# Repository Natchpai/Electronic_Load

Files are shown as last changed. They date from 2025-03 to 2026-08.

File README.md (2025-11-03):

# DC Electronic Loads Class Project

> A DC electronic load is a test instrument that simulates an electronic load to test the performance of a power source.

This project is **ESP32-Base** (I use esp32 because the processor's clock is fast than ATMega328 on Arduino Family)
ESP32 generating a PWM signal to controls the Gate-Source Voltage of MOSFET to drawn current from a power source, Measurement the currrent and feedback to control loop.

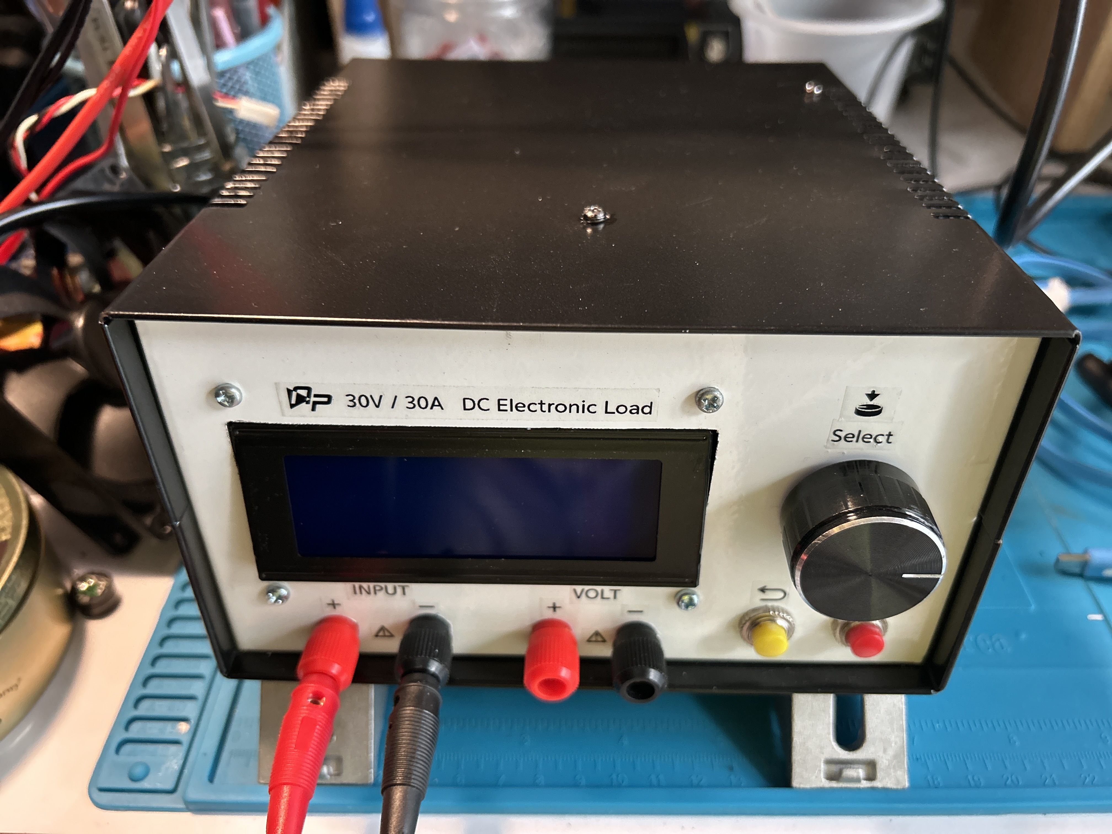
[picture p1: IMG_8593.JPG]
 

## Features
- Constant Current: Max 30A. *(I've only tested at 20A@12V. It works)*
- Constant Power
- Constant Resistance
- Digital Voltmeter(Add-on)

## 🛠️ How It Works
1. Sensing: A shunt resistor I use 0.1 Ohm. Measurement the current by read the voltage across this resister use Op-Amp (OP07)
2. Conversion: The Analog signal from Op-Amp is fed into an External ADC. This chip converts the voltage into a high-resolution digital value.
3. Control: ESP32 reads this digital value from the ADC. Compares this current to set-point and Find the difference between them. It called error.
   A PI controller algorithm running on the ESP32 calculates the exact adjustment needed to eliminate this error.
4. Result: The PI controller's output is a new PWN duty cycle. send to 2nd-order Low pass filter to give the dc level to Gate of MOSFET.

## 🛠️ Schematics
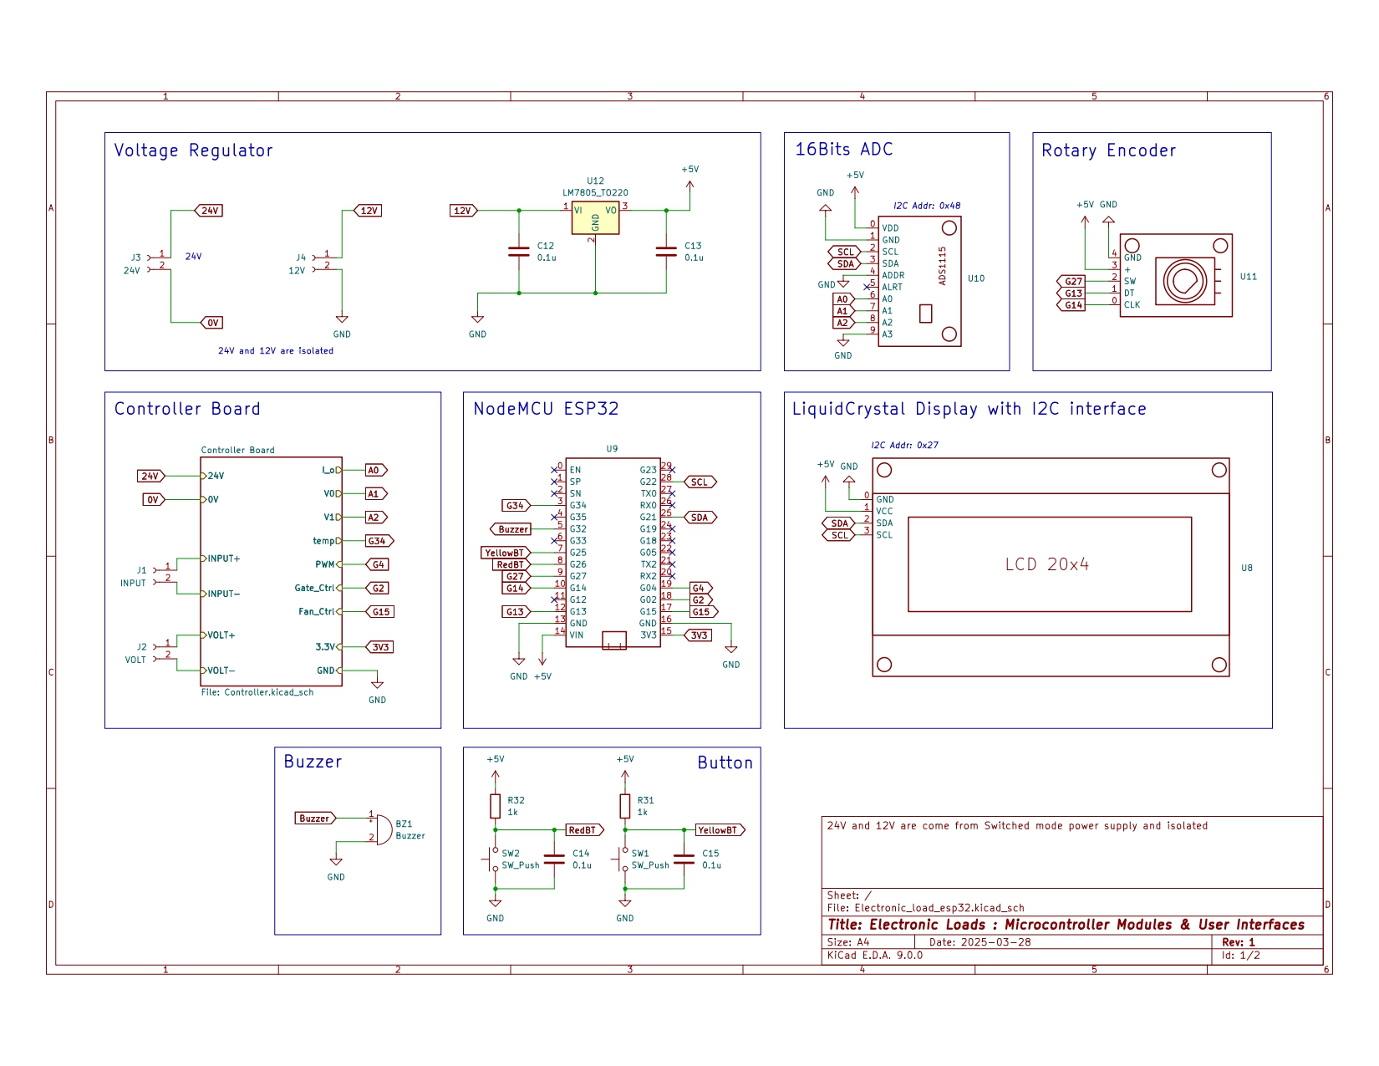
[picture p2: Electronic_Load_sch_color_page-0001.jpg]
sch1

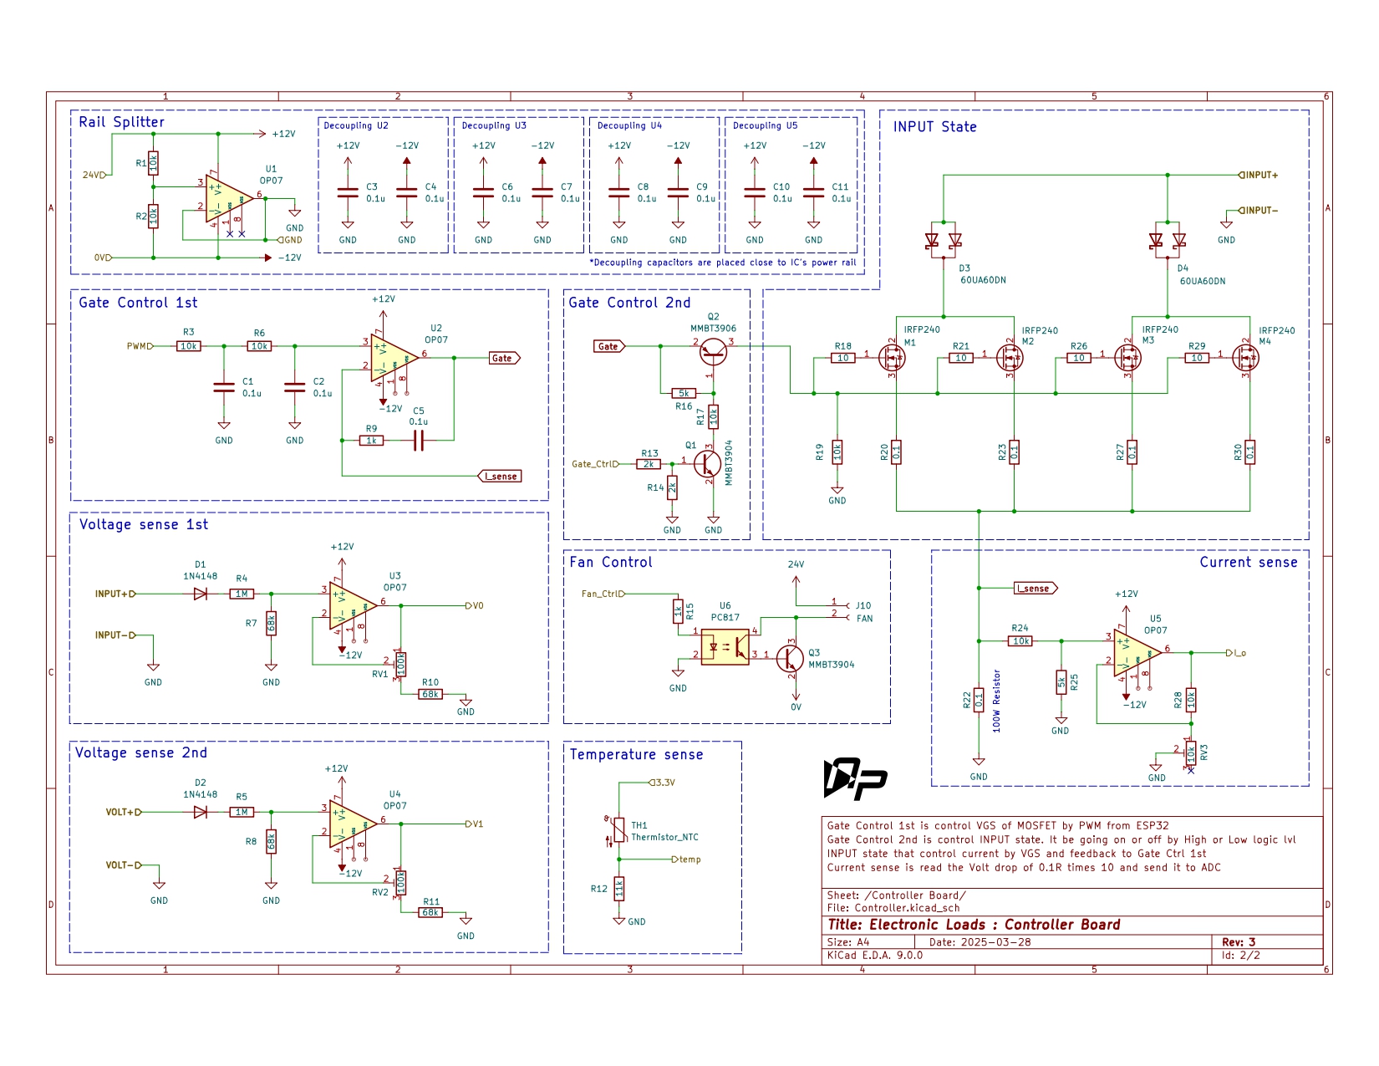
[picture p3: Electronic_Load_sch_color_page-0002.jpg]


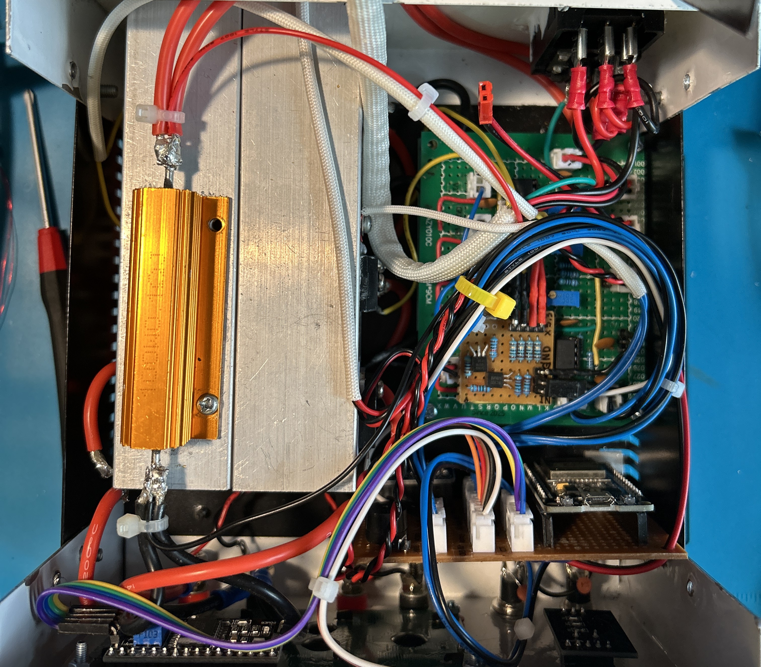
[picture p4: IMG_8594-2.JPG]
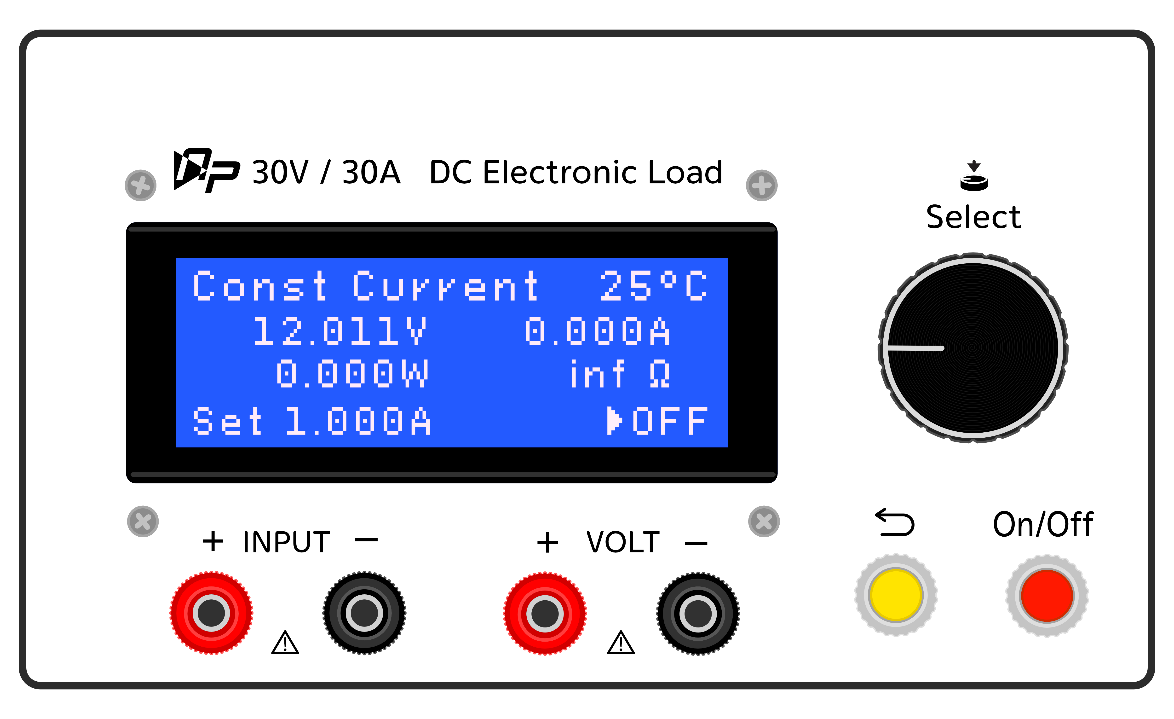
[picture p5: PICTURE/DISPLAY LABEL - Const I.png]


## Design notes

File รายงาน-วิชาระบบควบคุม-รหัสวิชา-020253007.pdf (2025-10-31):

### รายงานวิชาระบบควบคุม รหัสวิชา 0202533007

### เรื่อง โหลดอิเล็กทรอนิกส์ส าหรับไฟฟ้ากระแสตรง

จัดท าโดย

นาย ณัฐชนน เถื่อนถ ้า | 6602027620099
นาย ศิวกร เลิศทวีวัฒนา | 6602027620188
นาย พงศกร วุฒิเวสารัช | 6602027620111

ที่ปรึกษา

ผู้ช่วยศาสตราจารย์ ดร.ชัยยพล ธงชัยสุรัชต์กูล

รายงานนี้เป็นส่วนหนึ่งของวิชาระบบควบคุม

ภาควิชาครุศาสตร์ไฟฟ้า

คณะครุศาสตร์อุตสาหกรรม

มหาวิทยาลัยเทคโนโลยีพระจอมเกล้าพระนครเหนือ

ปีการศึกษา 2567

ก

บทคัดย่อ

โหลดอิเล็กทรอนิกส์กระแสตรง (DC Electronic Loads) เป็นอุปกรณ์ที่ใช้จ ำลองภำระในระบบไฟฟ้ำ กระแสตรงเพื่อทดสอบแหล่งจ่ำยไฟ แบตเตอรี่ เซลล์เชื้อเพลิง และอุปกรณ์อิเล็กทรอนิกส์อื่นๆ โดยสำมำรถปรับ ค่ำกระแส แรงดัน และพลังงำนได้ตำมต้องกำร โหลดอิเล็กทรอนิกส์สำมำรถท ำงำนในหลำยโหมด เช่น โหมดกระแส คงที่ (CC) โหมดก ำลังไฟฟ้ำคงที่ (CP) และโหมดควำมต้ำนทำนคงที่ (CR) ท ำให้สำมำรถจ ำลองกำรใช้งำนที่แตกต่ำง กันได้

กลุ่มของพวกกระผมจึงท ำกำรออกแบบและพัฒนำโหลดอิเล็กทรอนิกส์ที่มีควำมส ำคัญต่ออุตสำหกรรม อิเล็กทรอนิกส์และพลังงำนและยังสอดคล้องกับคณะที่พวกกระผมก ำลังศึกษำ ควำมส ำคัญของโหลดอิเล็กทรอนิกส์ นั่นคือกำรทดสอบประสิทธิภำพและควำมน่ำเชื่อถือของแหล่งจ่ำยไฟฟ้ำ กำรศึกษำครั้งนี้จึงมุ่งเน้นกำรออกแบบ โหลดอิเล็กทรอนิกส์ที่สำมำรถควบคุมได้อย่ำงแม่นย ำผ่ำนไมโครคอนโทรลเลอร์ พร้อมทั้งน ำเสนอกำรวิเครำะห์ สมรรถนะของระบบ ภำยใต้สภำวะโหลดต่ำงๆ

คณะผู้จัดท า

ข

สารบัญ

เรื่อง | หน้า
บทคัดย่อ | ก
สารบัญ | ข

ค

ง

บทที่1

บทน า

### 1. ความเป็นมาและความส าคัญ

ที่มำของโครงงำนเนื่องด้วยข้ำพเจ้ำสังเกตเห็นกลุ่มโครงงำนอื่นได้จัดท ำอุปกรณ์แหล่งจ่ำยข้ำพเจ้ำจึง ตระหนักว่ำในเมื่อมีแหล่งจ่ำยก็ต้องมีโหลดจึงได้จัดท ำโหลดอิเล็กทรอนิกส์ส ำหรับแหล่งจ่ำยไฟตรงซึ่งใช้หำ ประสิทธิภำพก่อนน ำไปใช้งำนจริง และทดสอบระบบของแหล่งจ่ำยว่ำท ำงำนได้อย่ำงมีประสิทธิภำพตำมที่ ออกแบบ ส ำคัญคือ อิเล็กทรอนิกส์โหลดในท้องตลำดนั้นมีรำคำค่อนข้ำงสูง ด้วยเหตุนี้จึงได้เป็นส่วนหนึ่งในที่มำ ของโครงงำนนี้คือ กำรสร้ำงอิเล็กทรอนิกส์โหลดที่สำมำรถให้งำนได้จริงในรำคำที่จับต้องได้

### 2. วัตถุประสงค์ของโครงงาน

2.1 อิเล็กทรอนิกส์โหลดที่สำมำรถให้งำนได้จริงในรำคำที่จับต้องได้

สร้ำงและออกแบบอุปกรณ์เครื่องมือวัดทำงไฟฟ้ำที่สำมำรถใช้งำนได้จริง

2.2 ทดสอบแหล่งจ่ำยพลังงำนไฟฟ้ำ

โหลดอิเล็กทรอนิกส์ช่วยให้สำมำรถทดสอบกำรท ำงำนของแหล่งจ่ำยไฟฟ้ำได้อย่ำงมีประสิทธิภำพ เช่น ตรวจสอบเสถียรภำพของแรงดันและกระแส รวมถึงผลตอบสนองของวงจรเมื่อมีกำรเปลี่ยนแปลง โหลด

2.3 พัฒนำทักษะด้ำนอิเล็กทรอนิกส์และกำรควบคุมระบบ

โครงงำนนี้ช่วยให้นักศึกษำและนักพัฒนำได้เรียนรู้กำรออกแบบวงจรไฟฟ้ำ กำรใช้ออปแอมป์ กำร ใช้มอสเฟต และเทคนิคกำรควบคุมระบบ เช่น PID Controller ในกำรปรับปรุงกำรท ำงำนของระบบ

### 3. ขอบเขตการท าโครงงาน

3.1 กระแสสูงสุด

สำมำรถรับได้สูงสุด 30 แอมแปร์ เนื่องจำกกระแสยิ่งสูง พลังงำนที่ต้องเปลี่ยนเป็นควำมร้อนยิ่งมี มำก ท ำให้เกิดควำมร้อนสูงภำยในชิ้นงำน และข้อจ ำกัดของชิ้นงำนที่มีขนำดเล็ก

3.2 แรงดันสูงสุด

สำมำรถรับได้สูงสุด 30 โวลต์ เนื่องจำกต้องกำรควำมแม่นย ำในกำรวัดแรงดันจึงจ ำเป็นต้องลดย่ำน วัดยิ่งย่ำนวัดยิ่งกว้ำงควำมแม่นย ำยิ่งต ่ำ แต่สำมำรถแก้ได้ด้วยกำรสร้ำงหลำยย่ำนวัด ซึ่งอยู่เหนือขอบเขต ของโครงงำน

### 4. สมมุติฐานการทดลอง

4.1 ตัวแปรต้น

แรงดัน ที่ใช้ควบคุมกระแสอินพุตให้สัมพันธ์กับฟังก์ชันกำรใช้งำน เช่น ต้องกำรกระแสอินพุต 1 แอมแปร์ (A) ต้องให้แรงดันกับระบบ 1 มิลลิโวลต์(mV)

4.2 ตัวแปรตำม

กระแสอินพุต จำกกำรใช้แรงดันควบคุมระบบให้สัมพันธ์กับฟังก์ชันกำรใช้งำน เช่น ให้แรงดันกับ ระบบ 1 มิลลิโวลต์(mV) จะได้กระแสอินพุต 1 แอมแปร์(A)

4.3 ตัวแปรควบคุม

อุณหภูมิที่เปลี่ยนแปลง ควำมร้อนที่เกิดขึ้นในระบบท ำให้กระแสอินพุตเปลี่ยนแปลงตำมอุณหภูมิ

บทที่ 2

เอกสารที่เกี่ยวข้อง

### 1. รายการอุปกรณ์

### 1.1 มอสเฟต (MOSFET)

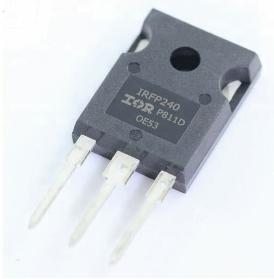
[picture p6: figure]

มอสเฟต เป็นทรำนซิสเตอร์ ที่ใช้อิทธิพลสนำมไฟฟ้ำในกำรควบคุมสัญญำณไฟฟ้ำ โดยใช้ออกไซด์ของ โลหะในกำรท ำ นิยมใช้เป็นสวิตช์เปิด-ปิดในวงจรอิเล็กทรอนิกส์ใช้ในวงจร Switching Power Supply และวงจรควบคุมโหลด

### 1.2 ออปแอมป์ (Op Amp)

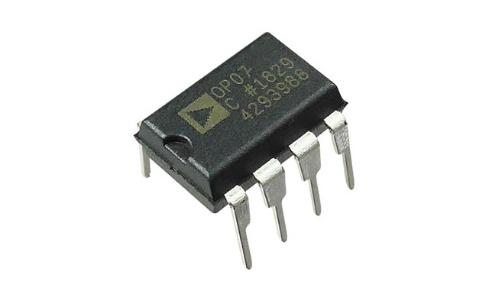
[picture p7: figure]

ออปแอมป์หรือ Operational Amplifier เป็นวงจรขยำยสัญญำณที่มีคุณสมบัติขยำยแรงดันไฟฟ้ำ และสำมำรถน ำไปใช้ในงำนด้ำนอิเล็กทรอนิกส์ได้หลำกหลำย เช่น

1. วงจรขยำยสัญญำณ ใช้ขยำยแรงดันจำกเซนเซอร์หรือไมโครโฟน
2. วงจรเปรียบเทียบแรงดัน ใช้ตรวจสอบระดับแรงดัน เช่น วงจรตรวจจับแรงดันแบตเตอรี่
3. วงจรควบคุม PID Controller หรือวงจรตำมแรงดัน ใช้ในระบบควบคุมอัตโนมัติ

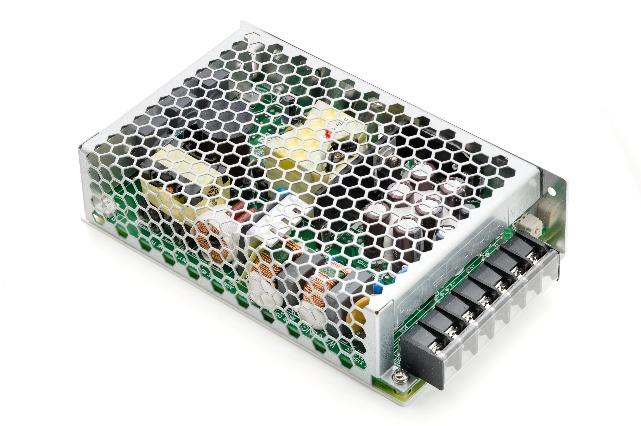
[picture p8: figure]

### 1.2 สวิตชิ่ง (Switched Mode Power Supply)

สวิตชิ่งพำวเวอร์ซัพพลำย หรือ แหล่งจ่ำยไฟฟ้ำแบบสวิตโหมด คือแหล่งจ่ำยไฟที่แปลงแรงดันไฟฟ้ำ โดยใช้หลักกำร เปิดปิดสวิตที่ควำมถี่สูง แทนกำรใช้หม้อแปลงขดลวดใหญ่ท ำให้มีประสิทธิภำพสูง ขนำด เล็ก และน ้ำหนักเบำ โดยมีหลำยแบบเช่น ลดแรงดัน เพิ่มแรงดัน หรือทั้งเพิ่มและทั้งลดแรงดัน เนื่องจำก ต้องสวิตที่ควำมถี่สูง ท ำให้เกิดสัญญำณรบกวนปะปนมำกับแรงดันขำออกด้วย

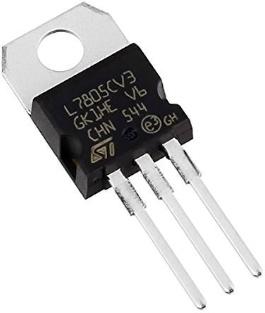
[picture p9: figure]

### 1.3 ไอซีเรกูเลเตอร์แบบเชิงเส้น (Linear Regulator IC)

เป็นวงจรควบคุมรักษำแรงดันไฟฟ้ำ หรือวงจรควบคุมกระแสไฟฟ้ำ ที่ย่อขนำดให้เล็กลงมำอยู่ใน ชิ้นส่วนอิเล็กทรอนิกส์ประเภทไอซี ที่ออกแบบมำเพื่อควบคุมรักษำแรงดันไฟฟ้ำ หรือกระแสไฟให้คงที่ มี ทั้งเอำต์พุตเป็นแรงดันไฟฟ้ำบวก หรือที่เอำต์พุตเป็นแรงดันไฟฟ้ำลบ ทั้งนี้ขึ้นอยู่กับกำรออกแบบสำมำรถ น ำไปใช้ควบคุม ซึ่งข้อดีของเรกูเลเตอร์แบบเชิงเส้นคือ ไม่ท ำให้เกิดสัญญำณรบกวนปะปนมำกับแรงดันขำ ออก

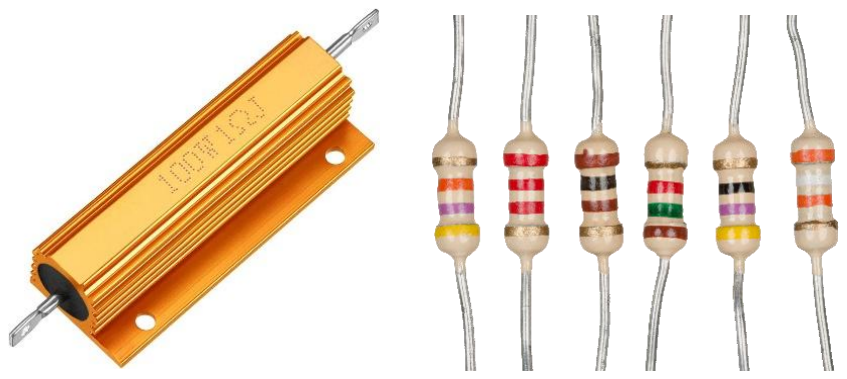
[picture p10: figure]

### 1.4 ตัวต้านทาน (Resistor)

เป็นอุปกรณ์ไฟฟ้ำชนิดหนึ่งที่มีคุณสมบัติในกำรต้ำนกำรไหลผ่ำนของกระแสไฟฟ้ำ ท ำหน้ำที่ลดค่ำ แรงดันไฟฟ้ำ และควบคุมปริมำณอัตรำกำรไหลของกระแสไฟฟ้ำในวงจร ตัวต้ำนทำนมีรูปแบบ และขนำด แตกต่ำงกันตำมลักษณะของกำรใช้งำน นอกจำกนี้ตัวต้ำนทำนที่ผลิตออกมำในปัจจุบันมีมำกมำยหลำย ชนิด น ำมำใช้ประกอบในวงจรทำงด้ำนไฟฟ้ำอิเล็กทรอนิกส์ทั่วไปอย่ำงแพร่หลำย ตัวอย่ำงเช่น เครื่องรับ วิทยุ เครื่องขยำยเสียง โทรทัศน์พำวเวอร์ซัพพลำย เป็นต้น

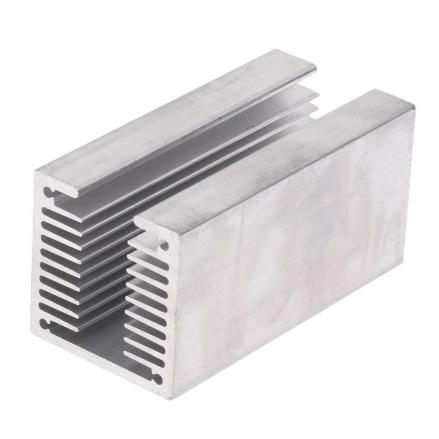
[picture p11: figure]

### 1.5 แผงระบายความร้อน (Heat sink)

แผงระบำยควำมร้อนในระบบอิเล็กทรอนิกส์ เป็นชิ้นส่วนซึ่งท ำหน้ำที่ลดอุณหภูมิขณะท ำงำนของ อุปกรณ์คอมพิวเตอร์หรืออุปกรณ์อิเล็กทรอนิกส์ โดยเพิ่มพื้นที่สัมผัสอำกำศ ท ำให้กำรพำควำมร้อนจำกตัว อุปกรณ์สู่อำกำศโดยรอบท ำได้เร็วขึ้น

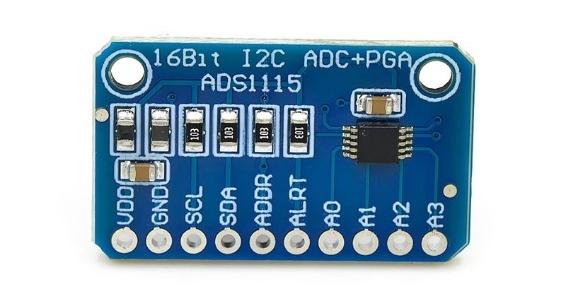
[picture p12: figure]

### 1.6 Analog to Digital Converter (ADC)

ท ำหน้ำที่แปลงสัญญำณแอนะล็อกเป็นลัญญำณดิจิทัล โดยควำมละเอียดนั้นขึ้นอยู่กับจ ำนวนบิตและ แรงดันอ้ำงอิง เช่น
16 บิด แรงดันอ้ำงอิง 4.096 โวลต์สำมำรถหำคงำมละเอียดได้โดย 2 ยกก ำลัง 15ได้ 32,768 และน ำไปหำร 4.096 จะได้ควำมละเอียดคือ 0.000125 โวลต์ต่อ 1 บิต
0000 0000 0000 0001 อ่ำนได้ 0.000125 * 1 แปลงได้ 125 ไมโครโวลต์
0000 0000 0000 0010 อ่ำนได้ 0.000125 * 2 แปลงได้ 250 ไมโครโวลต์
0000 0000 0000 0111 อ่ำนได้ 0.000125 * 7 แปลงได้875 ไมโครโวลต์

### 1.8 NodeMCU ESP32

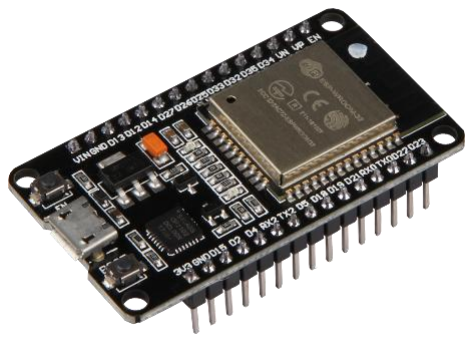
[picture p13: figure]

เป็นบอร์ดไมโครคอนโทรเลอร์ใช้กันอย่ำงแพร่หลำยที่ สำมำรถน ำไปพัฒนำโปรเจ็คได้หลำกหลำย รองรับกำรเชื่อมต่อ Wi-Fi และ Bluetooth ได้โดยไม่ต้องซื้อโมดูลเพิ่มเติม บอร์ด ESP32 เองยังมีกำร
ท ำงำนที่แบ่งเป็น 2 Core และ Pin I/O เลือกฟังก์ชันกำรท ำงำนได้ใน Pin เดียวกัน เช่น กำรแปลง Analog to Digital หรือ Digital to Analog กำรเชื่อมต่อ SD Card หรือ กล้องดิจิทัล ซึ่งสำมำรถเขียน โปรแกรม ผ่ำน Arduino IDE เหมือนเขียน Arduino ได้ข้อดีของ ESP32 นั้นคือ ควำมเร็วมำกกว่ำ และมี ควำมจ ำมำกกว่ำบอร์ดของ Arduino บำงรุ่น

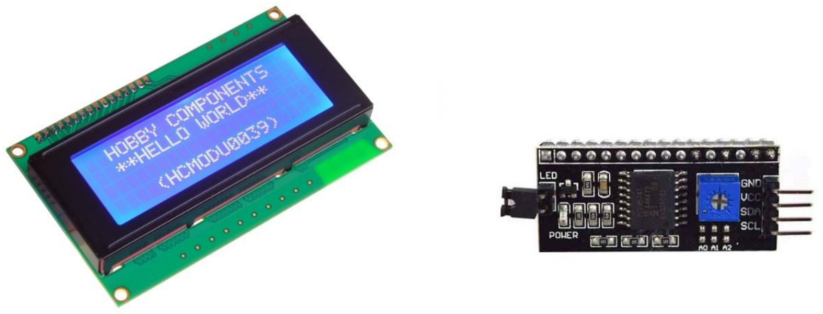
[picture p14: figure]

### 1.9 จอแสดงผล LCD ด้วยรูปแบบการสื่อสาร I²C

เป็นจอแสดงผลผ่ำนโมดูลแปลงรูปแบบกำรเชื่อมต่อแบบขนำนเป็นเชื่อมต่อแบบอื่นที่ใช้สำยน้อย ผ่ำน โปรโตคอล I2C ใช้เพียง 4 เส้น ก็ท ำให้หน้ำจอแสดงผลข้อควำมต่ำงๆออกมำได้

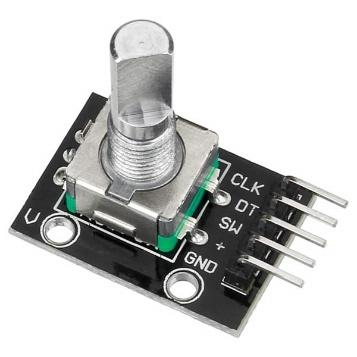
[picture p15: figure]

### 1.10 ตัวเข้ารหัสแบบหมุน (Rotary Encoder)

เป็นอุปกรณ์ไฟฟ้ำกล ที่แปลงต ำแหน่งเชิงมุม หรือกำรเคลื่อนที่ของเพลำหรือแกนหมุนเป็น สัญญำณไฟฟ้ำเอำต์พุต แบบแอนะล็อก หรือ ดิจิทัล

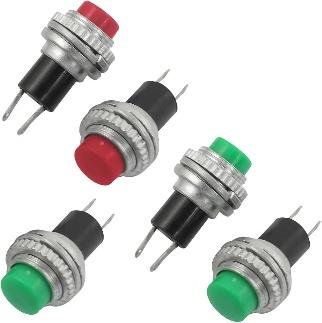
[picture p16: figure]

### 1.11 อินพุตและเอาต์พุตอื่นๆ

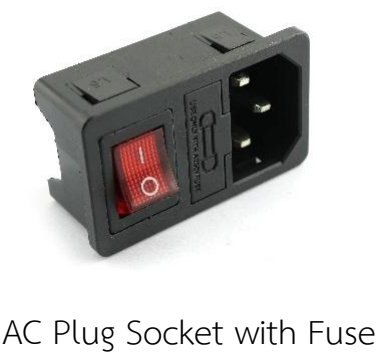
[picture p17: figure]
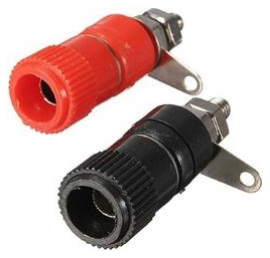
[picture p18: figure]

Push button | Banana Jack Female | AC Plug Socket with Fuse

บทที่ 3

วิธีการด าเนินงาน

### 1. หลักการของโหลดอิเล็กทรอนิกส์

โหลดอิเล็กทรอนิกส์ท ำงำนโดยใช้มอสเฟต (MOSFETs) เป็นตัวควบคุมปริมำณกระแสให้ไหลผ่ำน ตัวมันโดยตั้งใจให้ก ำลังสูญเสียทั้งหมดเกิดขึ้นที่ตัวมอสเฟต โดยก ำลังที่สูญเสียนั้นจะเปลี่ยนเป็นควำมร้อน โดยส่วนใหญ่แล้วมอสเฟตมักจะน ำไปใช้ในเป็นสวิตช์ในวงจรไฟฟ้ำ เช่น ในโซลิดสเตตรีเลย์ซึ่ง
ก ำลังสูญเสียจะค่อนข้ำงต ่ำเนื่องจำกตัวมอสเฟตเองไม่ได้เป็นโหลด โดยสำมำรถทดสอบได้จำกแรงกันตก ค่อมขำ Drain กับ Source เรียกว่ำ VDS คูณกับกระแสที่ไหลผ่ำนขำ Drain เรียกว่ำ ID ได้เป็นก ำลังสูญเสีย แต่ในโหลดอิเล็กทรอนิกส์นั้นไม่ได้ต้องกำรให้มอสเฟตเป็นสวิตช์แต่อย่ำงใด แต่ต้องกำรให้มอสเฟตเป็น โหลด โดยกำรต่อมอสเฟตขนำนกับอินพุต ให้แรงดัน VDS ได้สูงสุดหรือเท่ำกับอินพุต กำรควบคุมก ำลัง สูญเสียนั้นก็จะเหลือแค่กำรคุมกระแสให้ไหลผ่ำนมอสเฟตเท่ำนั้น โดยกำรควบคุมกระแสให้ไหลผ่ำนมอสเฟตได้ตำมต้องกำรนั้น สำมำรถท ำได้โดยกำรควบคุม แรงดันตกค่อมระหว่ำงขำ Gate และ Source เรียกว่ำ VGS โดยยิ่ง VGS มำก กระแสก็จะไหลผ่ำนได้มำก

### 2. การออกแบบ

กำรออกแบบโหลดอิเล็กทรอนิกส์นั้นได้ออกแบบโหมดกำรท ำงำนหลักไว้ 3 รูปแบบ คือ

### 1.1 โหมดกระแสคงที่ (Constant Current หรือ CC)

ท ำงำนโดยกำรควบคุม VGS เพื่อให้มอสเฟตน ำกระแสได้คงที่ตำมค่ำที่ใส่ลงไป

### 1.2 โหมดก าลังคงที่ (Constant Power หรือ CP)

ท ำงำนโดยกำรควบคุม VGS เพื่อให้มอสเฟตน ำกระแสให้สัมพันธ์กับแรงดันอินพุตที่เปลี่ยนไป ตำมสมกำร P = I * V

### 1.3 โหมดความต้านทานคงที่ (Constant Resistance หรือ CR)

ท ำงำนโดยกำรควบคุม VGS เพื่อให้มอสเฟตน ำกระแสให้สัมพันธ์กับแรงดันอินพุตที่เปลี่ยนไป ตำมสมกำร R = V / I

โดยสุดท้ำยแล้วทุกโหมดนั้นเกิดจำกกำรควบคุมกระแสให้ไหลผ่ำนมอสเฟตตำมต้องกำรทั้งสิ้น กำรควบคุมกระแสนั้น ตำมที่กล่ำวมำข้ำงต้นคือกำรควบคุมแรงดันเกตซอร์ซ (VGS) โดยได้ออกแบบระบบ ไว้โดยใช้ออปแอมป์เป็นตัวควบคุม คุณสมบัติอย่ำงง่ำยของออปแอมป์นั้นคือกำรรักษำแรงดันอินพุตบวกกับอินพุตลบให้เท่ำกันเสมอ ในวงปิด กำรใช้คุณสมบัตินี้มำคุมกำรไหลของกระแสได้โดยกำรอ่ำนกระแสที่ไหลในระบบแล้วแปลงเป็น แรงดันไฟฟ้ำส่งมำที่อินพุตของออปแอมป์ โดยกำรแปลงค่ำกระแสเป็นแรงดันนั้นสำมำรถท ำได้โดยกำรต่อ ตัวต้ำนทำนที่มีค่ำต ่ำ อนุกรมไปกับระบบที่ต้องกำรวัดกระแสแล้ววัดแรงดันตกค่อมตัวต้ำนทำนนั้น เช่น ต่อ ตัวต้ำนทำนขนำด 0.1 โอห์มอนุกรมไปกับระบบที่ต้องกำรวัดกระแส จำกนั้นวัดแรงดันตกค่อมตัวต้ำนทำน ถ้ำอ่ำนค่ำได้ 1 โวลต์ แสดงว่ำระบบนี้มีกระแสไหลทั้งหมด 10 แอมป์จำกกฎของโอห์ม กำรใช้คุณสมบัติของออปแอมป์นั้นท ำให้ง่ำยต่อกำรควบคุมระบบ เช่น ถ้ำต้องกำรกระแสไหล 1 แอมป์แสดงว่ำต้องจ่ำยแรงดันให้ออปแอมป์ 0.1 โวลต์เพื่อที่จะได้กระแสไหล 1 แอมป์ เพื่อที่จะได้ระบบที่มีเสถียรภำพมำกขึ้นจึงได้น ำตัวควบคุมพีไอดี(PID Controller) มำใช้ด้วย โดยตัวควบคุมนี้จะอยู่ในส่วนของโปรแกรมควบคุมในไมโครคอนโทรลเลอร์อีกที

ตัวควบคุมแบบสัดส่วน-ปริพันธ์-อนุพันธ์หรือ PID Controller เป็นระบบควบคุมแบบ ป้อนกลับ ซึ่งค่ำที่น ำไปใช้ในกำรค ำนวณเป็นค่ำควำมผิดพลำด มำจำกควำมแตกต่ำงของเอำต์พุตและค่ำที่ ต้องกำร ตัวควบคุมจะพยำยำมลดค่ำผิดพลำดให้เหลือน้อยที่สุด ค่ำ P I D จะขึ้นอยู่กับระบบที่น ำไป ควบคุม

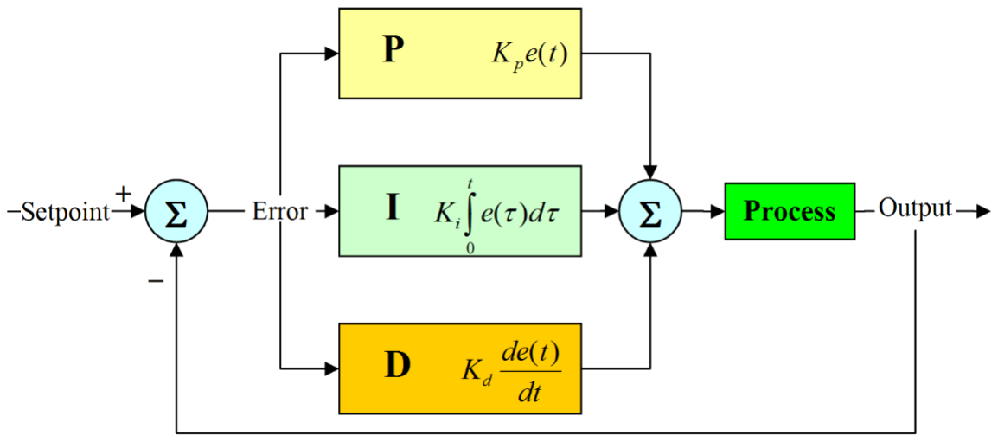
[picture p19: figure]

แผนภำพบล็อกของกำรควบคุมแบบพีไอดี

### 3. วงจร

### 4. การเลือกใช้งาน

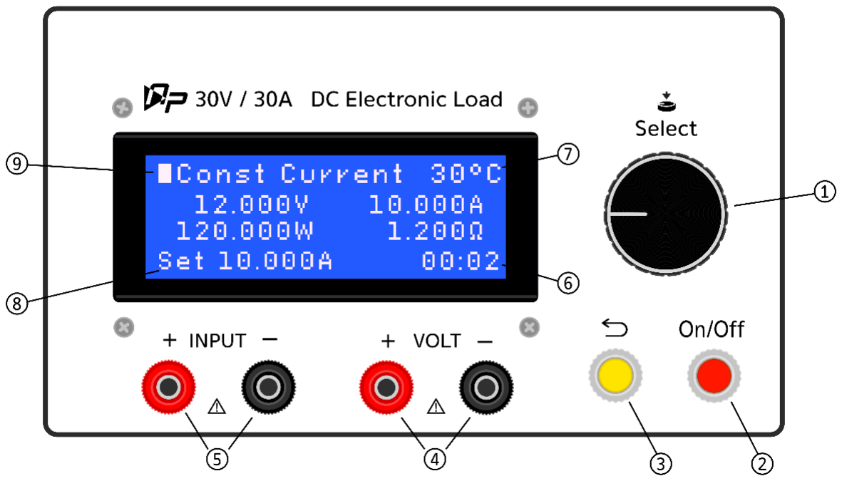
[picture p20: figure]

หมำยเลข 1 : ลูกบิด Select หมุนเพื่อเลื่อน กดเพื่อเลือก
หมำยเลข 2 : ปุ่ม On/Off กด หรือ กดค้ำง เพื่อเปิดกำรท ำงำนในโหมด CC CP และ CR หมำยเลข 3 : ปุ่มย้อนกลับ กด เพื่อ ย้อนกลับ กดค้ำงเพื่อเลือกได้
หมำยเลข 4 : Voltmeter CH1
หมำยเลข 5 : INPUT และ Voltmeter CH0
หมำยเลข 6 : เมื่อปิดจะแสดงค ำว่ำ OFF ถ้ำท ำงำนจะแสดงเวลำตั้งแต่เริ่มกำรท ำงำน หมำยเลข 7 : บอกอุณหภูมิของ Heat sink
หมำยเลข 8 : Setpoint หรือ ค่ำที่ต้องกำร สำมำรถตั้งได้ในโหมด CC CP และ CR หมำยเลข 9 : โหมดปัจจุบัน

### 4.1 Constant Current

1.1 กดปุ่มย้อนกลับเพื่อออกไปหน้ำเลือกฟังก์ชัน
1.2 หมุนลูกบิดให้ลูกศรชี้ที่ Const Current แล้วกดลูกบิด 1 ครั้งยืนยันกำรเลือก 1.3 ถ้ำต้องกำรตั้งค่ำกระแสให้กดลูกบิดอีก 1 ครั้ง เพื่องเข้ำเมนูI Setpoint
1.4 หมุนลูกบิดเลือกค่ำที่ต้องกำร ถ้ำต้องกำรเปลี่ยนหลักให้กดลูกบิด 1 ครั้ง
1.5 กดปุ่มย้อนกลับเพื่อยืนยันค่ำ แล้วเมนูจะเปลี่ยนเป็น Const Current
1.6 กดปุ่ม On/Off เพื่อเปิดหรือปิดใช้งำนโหมดนั้น

### 4.2 Constant Power

1.1 กดปุ่มย้อนกลับเพื่อออกไปหน้ำเลือกฟังก์ชัน
1.2 หมุนลูกบิดให้ลูกศรชี้ที่ Const Power แล้วกดลูกบิด 1 ครั้งยืนยันกำรเลือก 1.3 ถ้ำต้องกำรตั้งค่ำกระแสให้กดลูกบิดอีก 1 ครั้ง เพื่องเข้ำเมนูPower Setpoint 1.4 หมุนลูกบิดเลือกค่ำที่ต้องกำร ถ้ำต้องกำรเปลี่ยนหลักให้กดลูกบิด 1 ครั้ง
1.5 กดปุ่มย้อนกลับเพื่อยืนยันค่ำ แล้วเมนูจะเปลี่ยนเป็น Const Power
1.6 กดปุ่ม On/Off เพื่อเปิดหรือปิดใช้งำนโหมดนั้น

### 4.3 Constant Resistance

1.1 กดปุ่มย้อนกลับเพื่อออกไปหน้ำเลือกฟังก์ชัน
1.2 หมุนลูกบิดให้ลูกศรชี้ที่ Const Resistance แล้วกดลูกบิด 1 ครั้งเพื่อยืนยันกำรเลือก 1.3 ถ้ำต้องกำรตั้งค่ำกระแสให้กดลูกบิดอีก 1 ครั้ง เพื่องเข้ำเมนูR. Setpoint
1.4 หมุนลูกบิดเลือกค่ำที่ต้องกำร ถ้ำต้องกำรเปลี่ยนหลักให้กดลูกบิด 1 ครั้ง
1.5 กดปุ่มย้อนกลับเพื่อยืนยันค่ำ แล้วเมนูจะเปลี่ยนเป็น Constant R.
1.6 กดปุ่ม On/Off เพื่อเปิดหรือปิดใช้งำนโหมดนั้น

### 4.4 Digital Voltmeter

1.1 กดปุ่มย้อนกลับเพื่อออกไปหน้ำเลือกฟังก์ชัน
1.2 หมุนลูกบิดให้ลูกศรชี้ที่ Digital Voltmeter แล้วกดลูกบิด 1 ครั้งยืนยันกำรเลือก 1.3 CH0 วัดจำกช่อง INPUT
1.4 CH1 วัดจำกช่อง VOLT

### 4.5 Utility

1.1 กดปุ่มย้อนกลับเพื่อออกไปหน้ำเลือกฟังก์ชัน
1.2 หมุนลูกบิดให้ลูกศรชี้ที่ Utility แล้วกดลูกบิด 1 ครั้งยืนยันกำรเลือก 1.3 เลือกโดยให้ลูกศรชี้เมนูที่ต้องกำรกดลูกบิด 1 ครั้งยืนยันกำรเลือก

### 4.5.1 Current Max (Default: 20.000A)

เป็นกำรตั้งค่ำกระแสสูงสุดที่ระบบสำมำรถท ำได้ถ้ำใส่ค่ำเกิดในเมนูอื่นๆ กระแสจะไม่เกิน Current Max โดยสำมำรถตั้งได้ 0A – 30A

### 4.5.2 Volt sense (Default: V0)

เป็นกำรเลือก Voltmeter ส ำหรับวัดค่ำแรงดันในโหมด CC CP และ CR
V0 : INPUT เป็น Voltmeter ที่อยู่ในช่อง INPUT
V1 : VOLT เป็น Voltmeter ที่อยู่ในช่อง VOLT จะเป็นต้องต่อสำยวัดเพิ่ม

### 4.5.3 Fan Trig (Default: Auto)

เลือกกำรท ำงำนของพัดลมละบำยควำมร้อน
Auto พัดลมจะท ำงำนเมื่ออุณหภูมิถึง 45°C และจะปิดเมื่ออุณหภูมิลดลงจนถึง 35°C Manual พัดลมจะท ำงำนตำมกำรกดปุ่ม On/Off

### 4.5.4 Runtime Max (Default: 30min)

เป็นกำรตั้งค่ำเวลำ เมื่อโหมด CC CP และ CR ท ำงำนเกินเวลำนี้จะปิดกำรท ำงำนในโหมดนั้น

### 4.5.5 Shutdown Temp (Default: 90°C)

เป็นกำรตั้งค่ำอุณหภูมิสูงสุดภำยในเครื่อง ถ้ำเกิดอุณหภูมิเกินนี้จะปิดกำรท ำงำนในโหมดนั้น

### 4.6 PID Tuner

1.1 กดปุ่มย้อนกลับเพื่อออกไปหน้ำเลือกฟังก์ชัน
1.2 หมุนลูกบิดให้ลูกศรชี้ที่ PID Tuner แล้วกดลูกบิด 1 ครั้งยืนยันกำรเลือก
1.3 หมุนลูกบิดให้ลูกศรชี้ที่ค่ำที่ต้องกำรแล้วกดลูกบิด 1 ครั้งยืนยันกำรเลือก
หมำยเหตุ: ไม่แนะน ำให้ตั้งค่ำ Kp และ Kd ส่วน ค่ำ Ki เมื่อมำกจะท ำให้ระบบตอบสนองเร็วขึ้น ไม่แนะน ำให้เกิด 600 และต ่ำกว่ำ 100 *ค่ำเดิมอยู่ที่ 450

บทที่ 4

สรุปผลและข้อเสนอแนะ

### 1. สรุปผล

1.1 อิเล็กทรอนิกส์โหลดที่สำมำรถให้งำนได้จริงในรำคำที่จับต้องได้สร้ำงและออกแบบอุปกรณ์เครื่องมือวัด ทำงไฟฟ้ำที่สำมำรถใช้งำนได้จริง

1.2 ทดสอบแหล่งจ่ำยพลังงำนไฟฟ้ำโหลดอิเล็กทรอนิกส์ช่วยให้สำมำรถทดสอบกำรท ำงำนของแหล่งจ่ำย ไฟฟ้ำได้อย่ำงมีประสิทธิภำพ เช่น ตรวจสอบเสถียรภำพของแรงดันและกระแส รวมถึงผลตอบสนองของ วงจรเมื่อมีกำรเปลี่ยนแปลงโหลด

1.3 พัฒนำทักษะด้ำนอิเล็กทรอนิกส์และกำรควบคุมระบบ ช่วยให้นักศึกษำและนักพัฒนำได้เรียนรู้ กำรออกแบบวงจรไฟฟ้ำกำรใช้ออปแอมป์กำรใช้มอสเฟตและเทคนิคกำรควบคุมระบบ เช่น
PID Controller ในกำรปรับปรุงกำรท ำงำนของระบบ

### 2. ข้อเสนอแนะและปัญหาในการท างาน

2.1 ด้วยข้อจ ำกัดของชิ้นงำนที่มีขนำดเล็ก กำรท ำงำนด้วยกระแสสุดอำจจ ำให้เกิดควำมร้อนสะสมภำยใน จนอุปกรณ์เสียหำยได้

2.2 ด้วยย่ำนวัดแรงดันที่กว้ำงท ำให้กำรวัดแรงดันคลำดเคลื่อนจำกควำมเป็นจริงเล็กน้อย

2.3 ไม่สำมำรถใช้ควำมสำมำรถ Dual Core ของ ESP32 ได้ ถ้ำใช้ได้ระบบจะเร็วขึ้นอย่ำงเห็นได้ชัด

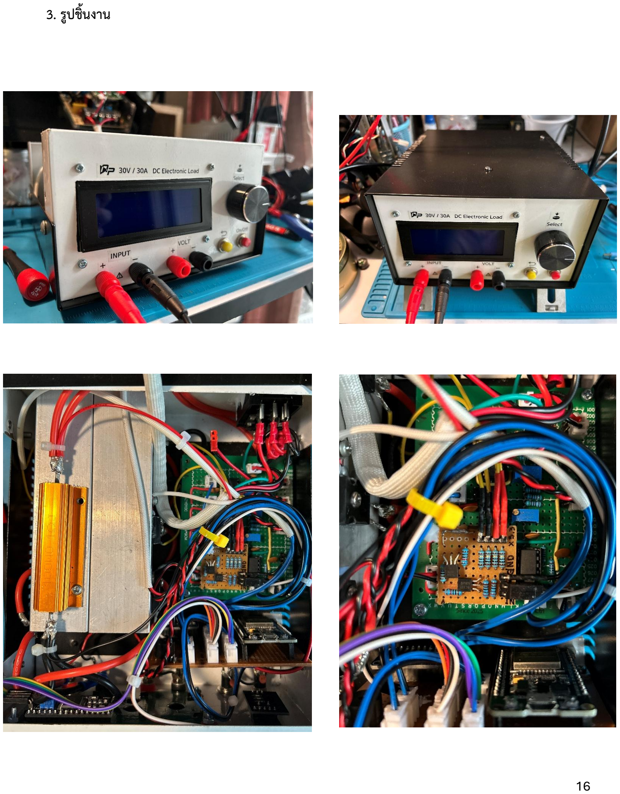
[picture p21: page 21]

### 3. รูปชิ้นงาน

บรรณานุกรม

https://en.wikipedia.org/wiki/Proportional%E2%80%93integral%E2%80%93derivative_controller

https://en.wikipedia.org/wiki/MOSFET

https://en.wikipedia.org/wiki/Operational_amplifier

https://en.wikipedia.org/wiki/Switchedmode_power_supply

https://en.wikipedia.org/wiki/Voltage_regulator

https://en.wikipedia.org/wiki/Resistor

https://en.wikipedia.org/wiki/Analog-to-digital_converter

https://en.wikipedia.org/wiki/ESP32

https://en.wikipedia.org/wiki/Rotary_encoder

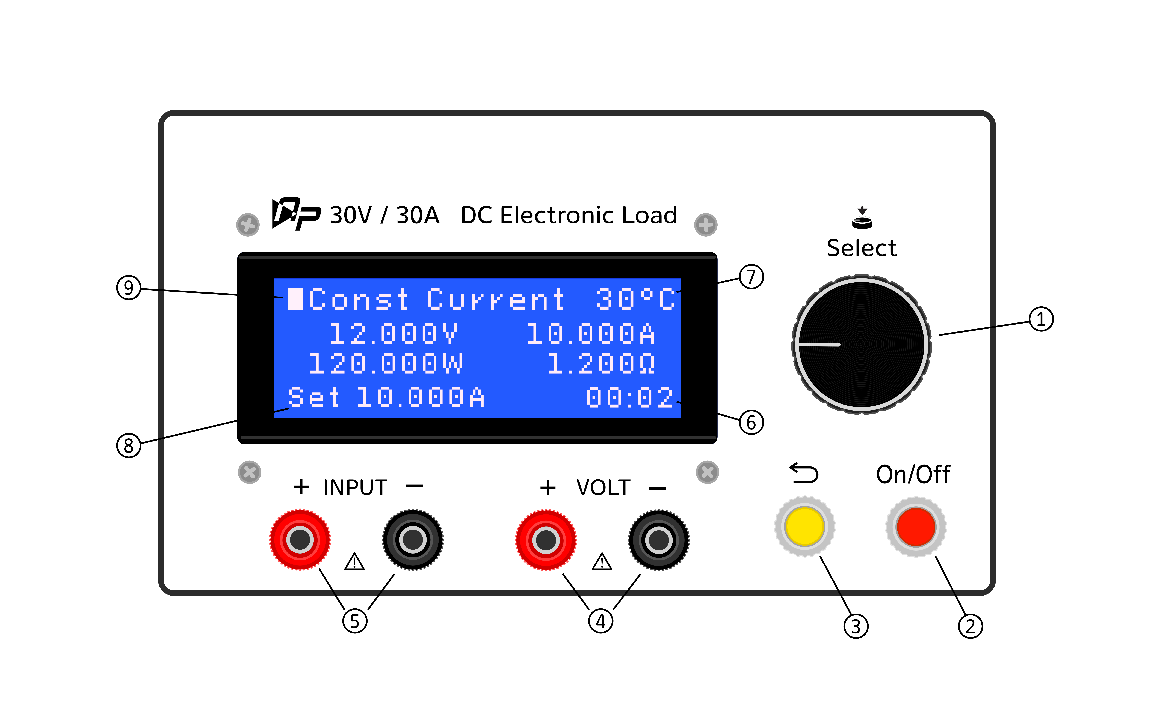
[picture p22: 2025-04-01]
PICTURE/DISPLAY LABEL - nemu_number.png

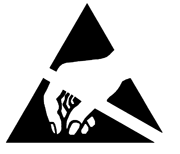
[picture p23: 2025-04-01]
logos/ESDsusceptibilitySymbol.png

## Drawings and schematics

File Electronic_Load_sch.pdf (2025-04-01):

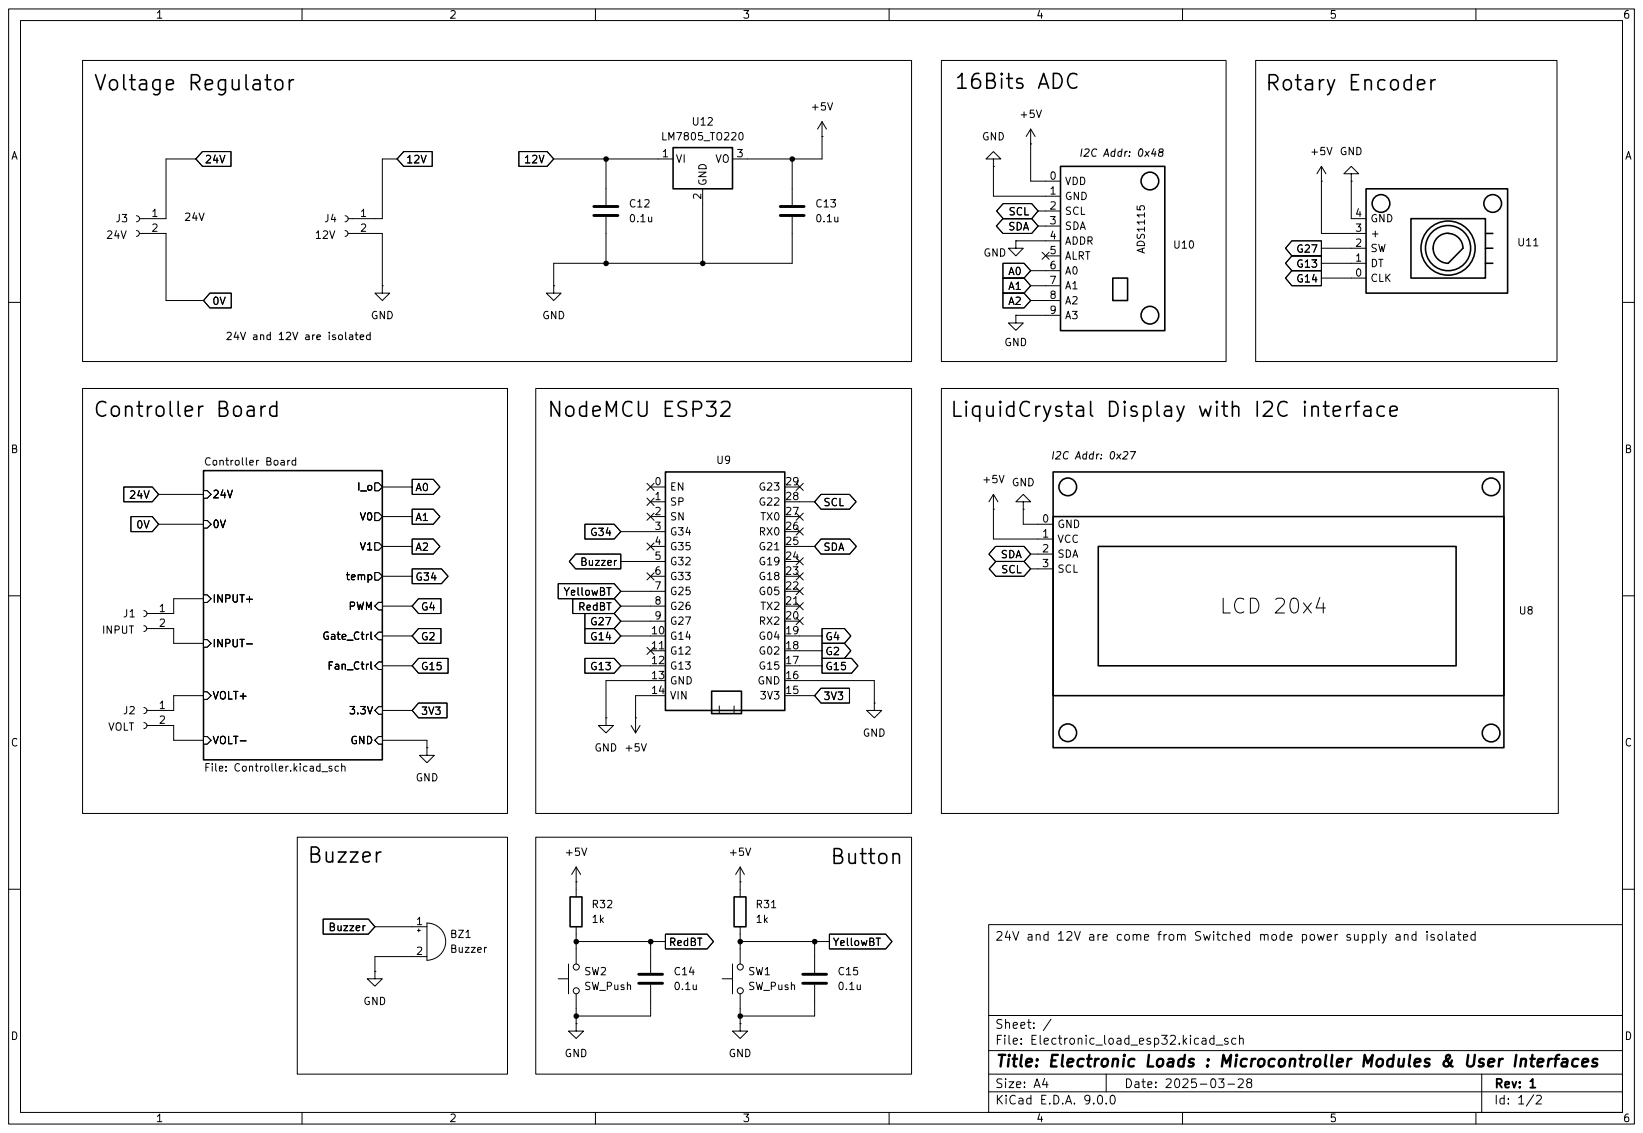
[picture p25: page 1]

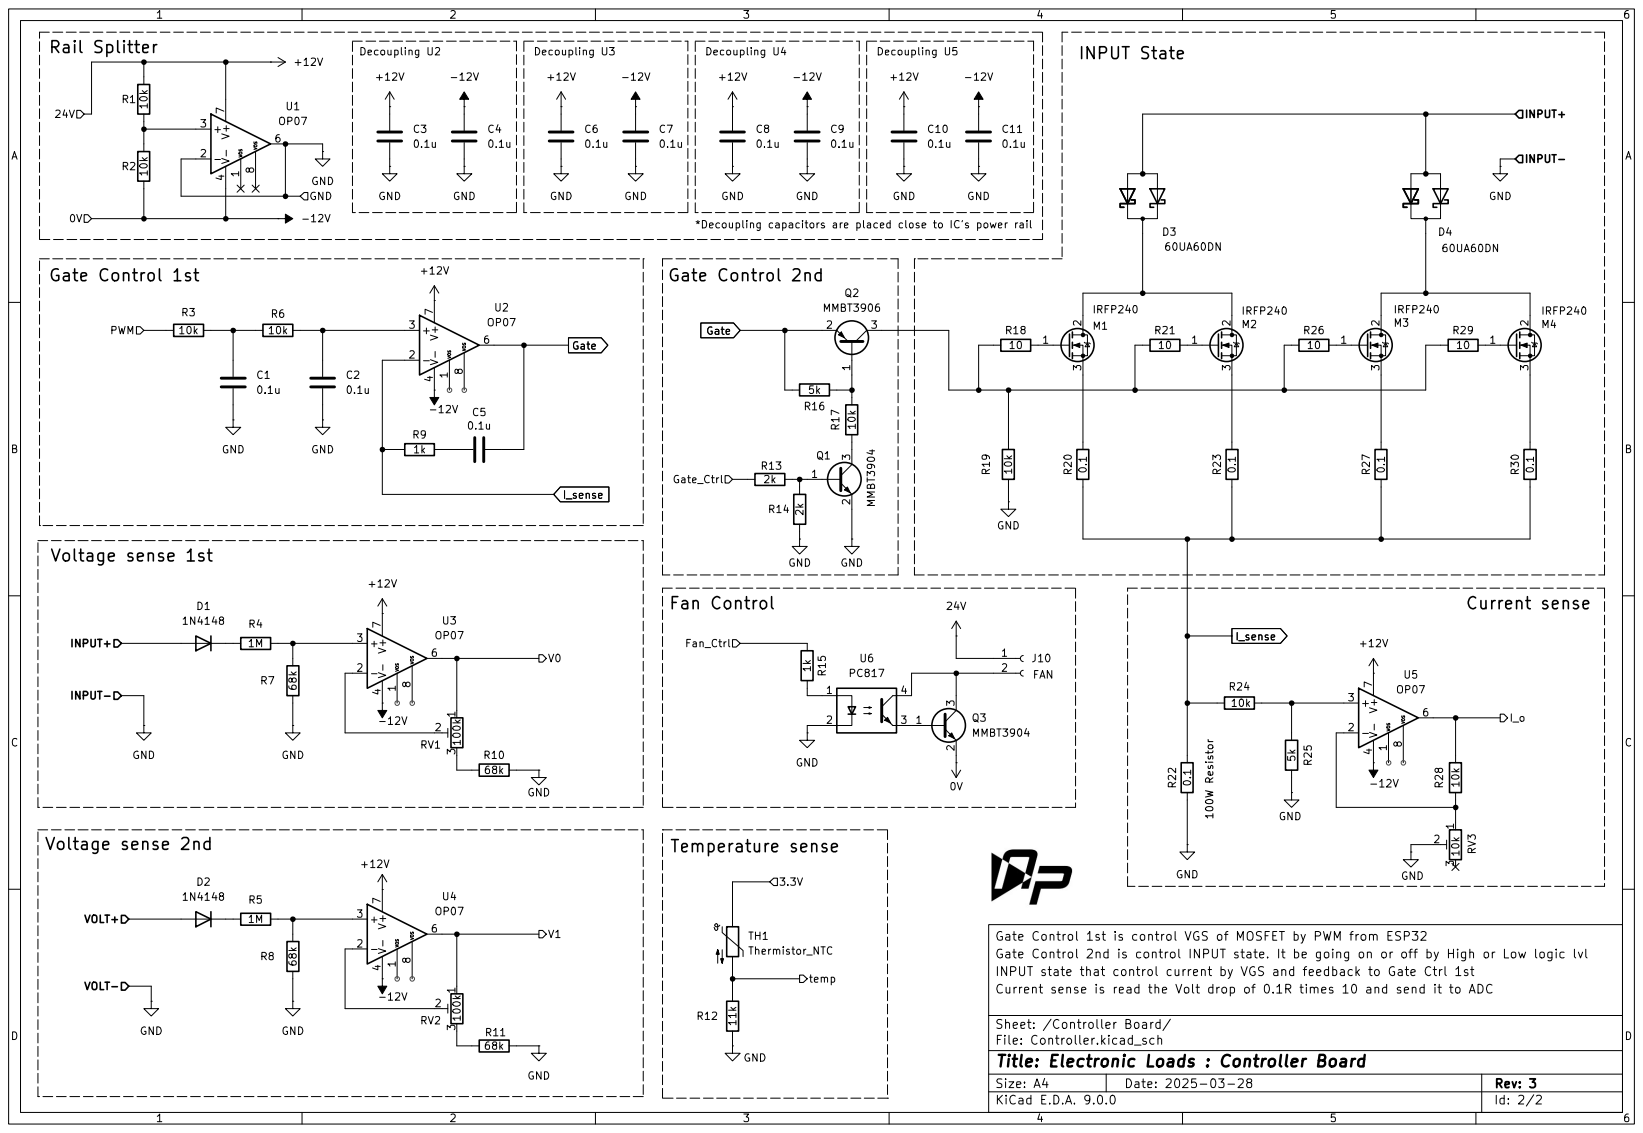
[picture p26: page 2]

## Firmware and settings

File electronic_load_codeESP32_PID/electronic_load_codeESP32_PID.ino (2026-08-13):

#include <math.h>

#include "ADS1X15.h"
#include "LiquidCrystal_I2C.h"
#include "BfButton.h"
#include "PID_v1.h"
// ADC INPUT
// Move to 16Bits ADC I2C bus at: 0x48
#define temp_sense_pin 34

#define buzzer_pin 32

// Digital INPUT
#define red_button_pin 26
#define yellow_button_pin 25
#define rotary_button_pin 27
#define Encoder_DT 13
#define Encoder_CLK 14

// Digital OUTPUT
#define PWM_pinOut 4
#define fanCtrl_pinOut 15
#define gateCtrl_pinOut 2

// Setting time
#define updateTemp_time 1000
#define updateSensor_time 500
#define updateVoltage_time 250

#define VIN_MIN 0.1

uint8_t sec = 0;
uint8_t minut = 0;
int timeMax = 30;
int timesetMax = 60;
int timesetmin = 0;
int TempsetMax = 125;
int Tempsetmin = 40;

uint32_t lastUpdateTempSensor;
uint32_t lastTime;
uint32_t LastupdateSensor;
uint32_t lastPressRedButton;
uint32_t lastBlink = 0;
uint32_t lastBlinkArrow = 0;

uint32_t clearDisplayFormMenu = 1;
bool drawSetValueFirstTime = 0;

bool encode_clk;
bool encode_dt;
bool rotaryIsNextTigger;

// Temp adj value
float beta = 3435;
float To = 298;
float R25 = 10000;
int8_t adj_temp = 0;
float CurrentTemp;
int FanTrig_TempUpper = 45;
int FanTrig_TempLower = 35;
bool FanTrig = false;
bool AutoFanMode = true;
int Temp_Max = 90;

// Parameter
bool onLoad = false;
bool loadFlag = 1;
uint32_t onLoad_time = 0;

double Iin_maximum = 20.00;

double IMax = 30.00;
double Imin = 00.00;
double Iset = 01.00;
double Iset_forCal = 0.00;

double PMax = 800.00;
double Pmin = 00.00;
double Pset = 0.00;

double RMax = 9999.9999;
double Rmin = 0.2;
double Rset = 50.00;

bool V_sense_number = 0; // Default at Input terminal
double V_sense_1st = 00.000;
double V_sense_2nd = 00.000;
double I_sense = 00.000;

double PowerOut = 0.000;
double Resistance = 0.000;
double V_sense_select = 0.000;

uint8_t select_digit = 3;

// Mode0 : Main menu
int menu = 1;
uint8_t frame = 1;
uint8_t mode = 0; // if 0 : Back to Main menu Auto
uint8_t previous_menu = 255;
uint8_t previous_mode = 255;

uint8_t digit_1 = 1;
uint8_t digit_2 = 2;
uint8_t digit_3 = 3;
int menuItemMax = 6;
int menuItemmin = 1;


//Define Variables we'll be connecting to
double Setpoint, Input, Output;

//Define the aggressive and conservative Tuning Parameters
// Don't touch Kd, it will be osscilate
double consKp=0.0, consKi=400, consKd=0.0;

double gainMax = 800.00;
double gainmin = 0.00;

PID calPID(&Input, &Output, &Setpoint, consKp, consKi, consKd, DIRECT);

String menuList[6] = {
  "Const Current     ",
  "Const Power       ",
  "Const Resistance  ",
  "Digital Voltmeter ",
  "Utility           ",
  "PID Tuner         ",
};

int menu_setting = 1;
int frame_setting = 1;
int cursor = 1;
int cursorMax = 2;
int cursormin = 1;


String settingList[6]= {
  "Current Max       ",
  "Volt sense        ",
  "Fan Trig          ",
  "Runtime Max       ",
  "Shutdown Temp     ",
  "                  ",
};

String onOffList[2] = {
  "ON                ",
  "OFF               "
};

String FanList[2] = {
  "Auto              ",
  "Manual            "
};


String PIDList[3]= {
  "Kp : ",
  "Ki :",
  "Kd : "
};

int cursorPIDMax = 3;
int cursorPIDmin = 1;
int menu_pid = 1;
int frame_pid = 1;


// Set PWM value
uint8_t resolution = 16;
uint16_t frequency = 1000;
uint16_t dutyCycle_Max = 65535;
uint16_t dutyCycle_min = 0;
int dutyCycle = 0;
float dutyFactor = 0;

// Analog to Digital Converter
ADS1115 ADS(0x48);
int16_t I_ADC ;
int16_t V0_ADC ;
int16_t V1_ADC ;

// LiquidCrystal set pin
LiquidCrystal_I2C lcd(0x27, 20, 4);

byte arrow[] = { // arrow >
  B01000,
  B01100,
  B01110,
  B01111,
  B01110,
  B01100,
  B01000,
  B00000
};

// byte subBar1[] = {B10000, B10000, B10000, B10000, B10000, B10000, B10000, B10000};
// byte subBar2[] = {B11000, B11000, B11000, B11000, B11000, B11000, B11000, B11000};
// byte subBar3[] = {B11100, B11100, B11100, B11100, B11100, B11100, B11100, B11100};
// byte subBar4[] = {B11110, B11110, B11110, B11110, B11110, B11110, B11110, B11110};
// byte subBar5[] = {B11111, B11111, B11111, B11111, B11111, B11111, B11111, B11111};

byte subBar1[] = {B00000, B00000, B10000, B10000, B10000, B10000, B10000, B10000};
byte subBar2[] = {B00000, B00000, B11000, B11000, B11000, B11000, B11000, B11000};
byte subBar3[] = {B00000, B00000, B11100, B11100, B11100, B11100, B11100, B11100};
byte subBar4[] = {B00000, B00000, B11110, B11110, B11110, B11110, B11110, B11110};
byte subBar5[] = {B00000, B00000, B11111, B11111, B11111, B11111, B11111, B11111};

// Button Fever
BfButton redButton(BfButton::STANDALONE_DIGITAL, red_button_pin, true, LOW); 
BfButton yellowButton(BfButton::STANDALONE_DIGITAL, yellow_button_pin, true, LOW); 
BfButton rotaryButton(BfButton::STANDALONE_DIGITAL, rotary_button_pin, false, LOW); 

void pressRed (BfButton *redButton, BfButton::press_pattern_t pattern) {
  switch (pattern) {
    case BfButton::SINGLE_PRESS:
      if(mode == 1) {
        onLoad = !onLoad;
      }
      break;
    case BfButton::DOUBLE_PRESS:
      break;
    case BfButton::LONG_PRESS:
      if(mode == 1) {
        onLoad = !onLoad;
        mode = 2;
      }
      break;
  }
}

void pressYellow (BfButton *yellowButton, BfButton::press_pattern_t pattern) {
  switch (pattern) {
    case BfButton::SINGLE_PRESS:
    // Back to previous
      if(mode != 0) mode = mode - 1;
      if(mode == 0) lcd.clear();
      
      break;
    case BfButton::DOUBLE_PRESS:
      
      break;
    case BfButton::LONG_PRESS:
      if(mode == 0) {
        mode = 1;
      }
      else if(mode == 1) {
        mode = 2;
      } 
      break;
  }
}

void pressRotary (BfButton *rotaryButton, BfButton::press_pattern_t pattern) {
  switch (pattern) {
    case BfButton::SINGLE_PRESS: 
      if(mode == 0) {
        mode = 1;
      }
      else if(mode == 1) {
        mode = 2;
      }  
      else if(mode == 2) {
        switch (menu) {
        case 1:
          if (select_digit != 4) {
            select_digit++;
          } else {
            select_digit = 0;
          }
          break;
        case 2:
          if (select_digit != 5) {
            select_digit++;
          } else {
            select_digit = 0;
          }
          break;
        case 3:
          if (select_digit != 6) {
            select_digit++;
          } else {
            select_digit = 0;
          }
          break;
        }
      }

      break;
    case BfButton::DOUBLE_PRESS:
      break;
    case BfButton::LONG_PRESS:
      break;
  }
}

////////////////////////////////////////// ROTARY ENCODER ///////////////////////////////////////
void printBegin() {
  lcd.setCursor(1, 1);
  lcd.print("DC Electronic Loads");
  lcd.setCursor(8, 3);
  lcd.print("2025");
  delay(3000);
}

void count_trig_float(double* value, uint8_t* digit, double* Max, double* min, bool up = true) { // digit 4 = X_.___, digit 1 = __._X_
  if(up == true) {
    switch (*digit) {
      case 0:
        if((*value + 0.001) > *Max) { *value = *Max; }
        else {*value = *value + 0.001;}
        break;
      case 1:
        if((*value + 0.01) > *Max) { *value = *Max; }
        else {*value = *value + 0.01;}
        break;
      case 2:
        if((*value + 0.1) > *Max) { *value = *Max; }
        else {*value = *value + 0.1;}
        break;
      case 3:
        if((*value + 1.0) > *Max) { *value = *Max; }
        else {*value = *value + 1.0;}
        break;
      case 4:
        if(((*value + 10.0) > *Max)) {}//{ *digits = *Max; }
        else {*value = *value + 10.0;}
        break;
      case 5:
        if(((*value + 100.0) > *Max)) {}//{ *digits = *Max; }
        else {*value = *value + 100.0;}
        break;
      case 6:
        if(((*value + 1000.0) > *Max)) {}//{ *digits = *Max; }
        else {*value = *value + 1000.0;}
        break;
      case 7:
        if(((*value + 10000.0) > *Max)) {}//{ *digits = *Max; }
        else {*value = *value + 10000.0;}
        break;
    }
  }
  else {
    switch (*digit) {
      case 0:
        if((*value - 0.001) < *min) { *value = *min; }
        else {*value = *value - 0.001;}
        break;
      case 1:
        if((*value - 0.01) < *min) { *value = *min; }
        else {*value = *value - 0.01;}
        break;
      case 2:
        if((*value - 0.1) < *min) { *value = *min; }
        else {*value = *value - 0.1;}
        break;
      case 3:
        if((*value - 1.0) < *min) {}//{ *value = *min; }
        else {*value = *value - 1.0;}
        break;
      case 4:
        if(((*value - 10.0) < *min)) {}//{ *value = *min; }
        else {*value = *value - 10.0;}
        break;
      case 5:
        if(((*value - 100.0) < *min)) {}//{ *value = *min; }
        else {*value = *value - 100.0;}
        break;
      case 6:
        if(((*value - 1000.0) < *min)) {}//{ *value = *min; }
        else {*value = *value - 1000.0;}
        break;
      case 7:
        if(((*value - 10000.0) < *min)) {}//{ *value = *min; }
        else {*value = *value - 10000.0;}
        break;  
      
    }
  }
}

void count_trig_int(int* value, uint8_t* digit, int* Max, int* min, bool up = true) { // digit 4 = X_.___, digit 1 = __._X_
  if(up == true) {
    switch (*digit) {
      case 1:
        if((*value + 1) > *Max) { *value = *Max; }
        else {*value = *value + 1;}
        break;
      case 2:
        if(((*value + 10.0) > *Max)) {}//{ *digits = *Max; }
        else {*value = *value + 10;}
        break;
    }
  }
  else {
    switch (*digit) {
      case 1:
        if((*value - 1) < *min) {}//{ *value = *min; }
        else {*value = *value - 1;}
        break;
      case 2:
        if(((*value - 10.0) < *min)) {}//{ *value = *min; }
        else {*value = *value - 10;}
        break;
    }
  }
}

void count(bool state = true) { // state is true : countup
  if(mode == 0) {
    // score main menu
    count_trig_int(&menu, &digit_1, &menuItemMax, &menuItemmin, !state);
  } else 
  
  if(mode == 2) {
    if(menu == 1) count_trig_float(&Iset, &select_digit, &IMax, &Imin, state);
    else if(menu == 2) count_trig_float(&Pset, &select_digit, &PMax, &Pmin, state);
    else if(menu == 3) count_trig_float(&Rset, &select_digit, &RMax, &Rmin, state);

    else if(menu == 5) {
      switch(menu_setting) {
        case 1:
          count_trig_float(&Iin_maximum, &select_digit, &IMax, &Imin, state);
          break;
        case 2:
          count_trig_int(&cursor, &digit_1, &cursorMax, &cursormin, !state);
          if(cursor == 1) V_sense_number = 0;
          else V_sense_number = 1;
          break;
        case 3:
          count_trig_int(&cursor, &digit_1, &cursorMax, &cursormin, !state);
          if(cursor == 1) AutoFanMode = true;
          else AutoFanMode = false;
          break;
        case 4:
          count_trig_int(&timeMax, &digit_1, &timesetMax, &timesetmin, state);
          break;
        case 5:
          count_trig_int(&Temp_Max, &digit_1, &TempsetMax, &Tempsetmin, state);
          break;
      }
    }

    else if(menu == 6) {
      if(menu_pid == 1) count_trig_float(&consKp, &digit_2, &gainMax, &gainmin, state);
      else if(menu_pid == 2) count_trig_float(&consKi, &digit_3, &gainMax, &gainmin, state);
      else if(menu_pid == 3) count_trig_float(&consKd, &digit_2, &gainMax, &gainmin, state);
      
    }

  } else 

  if(mode == 1) {
    if(menu == 5) count_trig_int(&menu_setting, &digit_1, &menuItemMax, &menuItemmin, !state);
    else if(menu == 6) count_trig_int(&menu_pid, &digit_1, &cursorPIDMax, &cursormin, !state);
  }
}

void rotaryEncode() {
  encode_clk = digitalRead(Encoder_CLK);
  encode_dt = digitalRead(Encoder_DT);
  if (encode_clk == 0 && encode_dt == 1 && rotaryIsNextTigger == 1) {
    rotaryIsNextTigger = 0;
    count(1);
    digitalWrite(buzzer_pin, HIGH); 
  } 
  else if(encode_dt == 0 && encode_clk == 1 && rotaryIsNextTigger == 1) {
    rotaryIsNextTigger = 0;
    count(0);
    digitalWrite(buzzer_pin, HIGH); 
  } 
  else if(encode_clk == 1 && encode_dt == 1 ) {
    rotaryIsNextTigger = 1;
    digitalWrite(buzzer_pin, LOW);
  }
}
////////////////////////////////////////// ROTARY ENCODER ///////////////////////////////////////

void readTemp() {
  float v_ntc = (analogRead(temp_sense_pin) * 3.3) / 4095;
  float R_ntc = ((3.3* 11000) / v_ntc) - 11000;
  CurrentTemp = ( (beta) / ( log(R_ntc/R25) + (beta/To)) ) - 273 + 4 + adj_temp;
}

void updateTempSensor() {
  // Tempurature sensor
  readTemp();
  if((int)CurrentTemp <= 99) {
    lcd.setCursor(15, 0);
    lcd.print(" ");
    lcd.setCursor(16, 0);
    lcd.print((int)CurrentTemp);
    lcd.setCursor(18, 0);
    lcd.print(char(223));
    lcd.setCursor(19, 0);
    lcd.print("C");
  }else{
    lcd.setCursor(15, 0);
    lcd.print((int)CurrentTemp);
    lcd.setCursor(18, 0);
    lcd.print(char(223));
    lcd.setCursor(19, 0);
    lcd.print("C");
  }
}

void readVoltageAll() {
  V0_ADC = ADS.readADC(1);  
  V1_ADC = ADS.readADC(2); 
  if (ADS.getError() == ADS1X15_OK)
  { 
    V_sense_1st = abs(V0_ADC * 0.001250);
    V_sense_2nd = abs(V1_ADC * 0.001250);
  }
}

void readSensor() {
  ADS.setGain(1); // Verf = 4.096 > Factor = 125uV / Bit;

  I_ADC = ADS.readADC(0);  
  V0_ADC = ADS.readADC(1);  
  V1_ADC = ADS.readADC(2);  

  if (ADS.getError() == ADS1X15_OK)
  { 

    I_sense = abs(I_ADC * 0.001250);
    if(V_sense_number == 0) {
      V_sense_select = abs(V0_ADC * 0.001250);
    }
    else {
      V_sense_select = abs(V1_ADC * 0.001250);
    }
  }

  // Power calculate
  PowerOut = I_sense * V_sense_select;

  // Resistance calculate
  if(I_sense != 0.0001) {
    Resistance = V_sense_select / I_sense;
  } else { Resistance = 1000000.0;}
  

  if(menu == 1 && V_sense_select >= VIN_MIN) {
    Iset_forCal  = Iset;
  }
  // if activate = 0 : PWM duty = 0
  else if(menu == 2 && V_sense_select >= VIN_MIN) {// Protection
    Iset_forCal  = Pset / V_sense_select;
  }
  else if(menu == 3 && Rset > 0.01) {// devide by zero
    Iset_forCal  = V_sense_select / Rset;
  }
  
  // Protection
  // if(Iset_forCal  > Iin_maximum) Iset_forCal = 1.0;
  if(V_sense_select < VIN_MIN) {
    Iset_forCal = 0; onLoad = 0;
  }

}

void updateSensor() {
  if( (menu == 1 ||  menu == 2 || menu == 3) && mode != 0 ) {
    if(millis() - lastUpdateTempSensor >= updateTemp_time) {
      lastUpdateTempSensor = millis();
      updateTempSensor();
    }

    if(millis() - LastupdateSensor >= updateSensor_time)
    {
      LastupdateSensor = millis();
    // Voltage display
      if(V_sense_select < 10.000) 
      {
        lcd.setCursor(2, 1);
        lcd.print(" ");
        lcd.setCursor(3, 1);
        lcd.print(V_sense_select, 3);
        lcd.setCursor(8, 1);
        lcd.print("V");
      }
      else 
      {
        lcd.setCursor(2, 1);
        lcd.print(V_sense_select, 3);
        lcd.setCursor(8, 1);
        lcd.print("V");
      }

    // Current Display 
      if(I_sense < 10.000) 
      {
        lcd.setCursor(11, 1);
        lcd.print(" ");
        lcd.setCursor(12, 1);
        lcd.print(I_sense, 3);
        lcd.setCursor(17, 1);
        lcd.print("A");
      }
      else 
      {
        lcd.setCursor(11, 1);
        lcd.print(I_sense, 3);
        lcd.setCursor(17, 1);
        lcd.print("A");
      }
      
    // Power Display 
      
      if(PowerOut < 10.000) 
      {
        lcd.setCursor(1, 2);
        lcd.print("  ");
        lcd.setCursor(3, 2);
        lcd.print(PowerOut, 3);
        lcd.setCursor(8, 2);
        lcd.print("W");
      }

      else if(PowerOut < 100.000) 
      {
        lcd.setCursor(1, 2);
        lcd.print(" ");
        lcd.setCursor(2, 2);
        lcd.print(PowerOut, 3);
        lcd.setCursor(8, 2);
        lcd.print("W");
      }
      else 
      {
        lcd.setCursor(1, 2);
        lcd.print(PowerOut, 3);
        lcd.setCursor(8, 2);
        lcd.print("W");
      }

    // Resistance Display

      if(Resistance< 10.0) 
      {
        lcd.setCursor(10, 2);
        lcd.print("  ");
        lcd.setCursor(12, 2);
        lcd.print(Resistance, 3);
        lcd.setCursor(17, 2);
        lcd.print(char(244));
        lcd.print(" ");
      }
      else if(Resistance < 100.0) 
      { 
        lcd.setCursor(10, 2);
        lcd.print(" ");
        lcd.setCursor(11, 2);
        lcd.print(Resistance, 3);
        lcd.setCursor(17, 2);
        lcd.print(char(244));
        lcd.print(" ");
      }
      else if(Resistance < 1000.0)
      {
        lcd.setCursor(10, 2);
        lcd.print(Resistance, 3);
        lcd.setCursor(17, 2);
        lcd.print(char(244));
        lcd.print(" ");
      }
      else if(Resistance < 10000.0){
        lcd.setCursor(10, 2);
        lcd.print("  ");
        lcd.setCursor(12, 2);
        lcd.print( (Resistance/1000.0) , 3);
        lcd.setCursor(17, 2);
        lcd.print("k");
        lcd.setCursor(18, 2);
        lcd.print(char(244));
        lcd.print(" ");
      } else {
        lcd.setCursor(10, 2);
        lcd.print("  inf  ");
        lcd.setCursor(17, 2);
        lcd.print(char(244));
        lcd.print(" ");
      }
    }
  }
}

void updateRunMode() {
  if(mode != 0) {
    if(onLoad == 1 && (millis() - lastPressRedButton >= 500)) {
      lastPressRedButton = millis();
      lcd.setCursor(15, 3);
      lcd.print(minut / 10);
      lcd.print(minut % 10);
      lcd.print(":");
      lcd.print(sec / 10);
      lcd.print(sec % 10);
    }
    if(onLoad == 0) {
      if(millis() - lastBlinkArrow >= 500) {
        lcd.setCursor(15, 3);
        lcd.print("  OFF");
      }
      if(millis() - lastBlinkArrow >= 1000) {
        lastBlinkArrow = millis();
        lcd.setCursor(15, 3);
        lcd.print(" ");
        lcd.write(0); // arrow
      }
      sec = 0; minut = 0; 
    }
  } 
  else 
  {
    sec = 0; minut = 0; 
  }
  digitalWrite(gateCtrl_pinOut, onLoad);
}

int lastNumSubBars1;
int lastNumSubBars2;

void printBar(float data, float maxData, int maxBars, uint8_t column, uint8_t row, int *lastNumSubBars) {

  int numSubBars = map(data, 0, maxData, 0, maxBars);

  if (numSubBars < *lastNumSubBars) {
    for (int i = numSubBars / 5 ; i < (*lastNumSubBars / 5) + 1; i++) {
        lcd.setCursor(i + column, row);
        lcd.print(" "); 
    }
  }

  lcd.setCursor(column, row);
  for (int i = 0; i < numSubBars / 5; i++) {
      lcd.write(5); 
  }

  int remainder = numSubBars % 5;
  if (remainder > 0) {
      lcd.write(remainder);
  }

  *lastNumSubBars = numSubBars;

}

void drawSetValue_setMode(float value, String txt, uint8_t digit) {
  lcd.setCursor(0, 3);
  lcd.print("Set");
  if(digit < 3) {
    if(value < 10.00) {
      lcd.setCursor(4, 3);
      lcd.print("0");
      lcd.setCursor(5, 3);
      lcd.print(value, 3);
      lcd.setCursor(10, 3);
      lcd.print(txt);
    } 
    else {
      lcd.setCursor(4, 3);
      lcd.print(value, 3);
      lcd.setCursor(10, 3);
      lcd.print(txt);
    }
  }
  else if(digit == 3) {
    if(value < 10.00) {
      lcd.setCursor(4, 3);
      lcd.print("00");
      lcd.setCursor(6, 3);
      lcd.print(value, 3);
      lcd.setCursor(11, 3);
      lcd.print(txt);
    } 
    else if(value < 100.00){
      lcd.setCursor(4, 3);
      lcd.print("0");
      lcd.setCursor(5, 3);
      lcd.print(value, 3);
      lcd.setCursor(11, 3);
      lcd.print(txt);
    }else{
      lcd.setCursor(4, 3);
      lcd.print(value, 3);
      lcd.setCursor(11, 3);
      lcd.print(txt);
    }
  }
  else if(digit == 4) {
    if(value < 10.00) {
      lcd.setCursor(4, 3);
      lcd.print("000");
      lcd.setCursor(7, 3);
      lcd.print(value, 3);
      lcd.setCursor(12, 3);
      lcd.print(txt);
    } 
    else if(value < 100.00){
      lcd.setCursor(4, 3);
      lcd.print("00");
      lcd.setCursor(6, 3);
      lcd.print(value, 3);
      lcd.setCursor(12, 3);
      lcd.print(txt);
    }
    else if(value < 1000.00){
      lcd.setCursor(4, 3);
      lcd.print("0");
      lcd.setCursor(5, 3);
      lcd.print(value, 3);
      lcd.setCursor(12, 3);
      lcd.print(txt);
    }
    else {
      lcd.setCursor(4, 3);
      lcd.print(value, 3);
      lcd.setCursor(12, 3);
      lcd.print(txt);
    }
  }
}

void drawSetValue_RunMode(float value, String txt) {
  lcd.setCursor(0, 3);
  lcd.print("Set");
  if(value < 10.00) {
    lcd.setCursor(4, 3);
    lcd.print(value, 3);
    // lcd.setCursor(12, 3);
    lcd.print(txt);
  } 
  else if(value < 100.00){
    lcd.setCursor(4, 3);
    lcd.print(value, 3);
    // lcd.setCursor(11, 3);
    lcd.print(txt);
  }
  else if(value < 1000.00){
    lcd.setCursor(4, 3);
    lcd.print(value, 3);
    // lcd.setCursor(12, 3);
    lcd.print(txt);
  }
  else {
    lcd.setCursor(4, 3);
    lcd.print((value/1000), 3);
    lcd.setCursor(12, 3);
    lcd.print("K");
    // lcd.setCursor(13, 3);
    lcd.print(txt);
  }
}

void menu0_MainMenu() {
  lcd.setCursor(0, 0);
  lcd.print(char(0xff));
  lcd.setCursor(1, 0);
  lcd.print("Select Function");

  rotaryEncode();
  rotaryButton.read();

  if(menu - frame == 3) {
    frame++;
  }

  else if(frame - menu == 1) {
    frame--;
  }
  
  lcd.setCursor(0, menu - frame + 1);
  lcd.write(0); 

  if (menu - frame == 0) {
    lcd.setCursor(0, 2);
    lcd.print(" "); 
    lcd.setCursor(0, 3);
    lcd.print(" "); 
    rotaryEncode();

  } 
  else if (menu - frame == 2) {
    lcd.setCursor(0, 1);
    lcd.print(" "); 
    lcd.setCursor(0, 2);
    lcd.print(" ");
    rotaryEncode();

  }
  else {
    lcd.setCursor(0, 1);
    lcd.print(" "); 
    lcd.setCursor(0, 3);
    lcd.print(" "); 
    rotaryEncode();
  }

  lcd.setCursor(1, 1);
  lcd.print(menuList[frame - 1]);
  lcd.setCursor(1, 2);
  lcd.print(menuList[frame + 0]);
  lcd.setCursor(1, 3);
  lcd.print(menuList[frame + 1]);
  rotaryEncode();
}
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
void loop() {
  readInput();
  runMenu();
  rotaryEncode();
  readSensor();
  
  // Set Duty cycle
  
  setDuty_PID();

  // Serial.print("duty:");
  // Serial.print(dutyCycle*0.00152);
  // Serial.print(",");

  


  // update sensor every 0.5 secconds
  updateSensor(); 
  if(menu == 1 || menu == 2 || menu == 3) {
    updateRunMode();
  }

  updateFanTrig(3000);
  
  rotaryEncode();

  clock_count();
}

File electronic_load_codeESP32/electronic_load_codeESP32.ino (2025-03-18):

#include <LiquidCrystal_I2C.h>

// GPIO34 ADC1
// GPIO35 ADC1
// GPIO32 ADC1
// GPIO33 ADC1
// GPIO25 ADC2
// GPIO26 ADC2

// Analog INPUT   : Current sense x1 , Voltage sense x2 , Temperature sense x1
// Digital INPUT  : Yellow_button x1, Red_button x1, Rotary_button x1, Rotary Encoder x1
// Digital OUTPUT : Current control with PWM 10KHz, Fan control
// Display        : LCD I2C Interface 16x4 

// ADC INPUT
//  Current sense     @ GPIO34
//  Voltage sense 1st @ GPIO35
//  Voltage sense 2nd @ GPIO32
//  Temperature sense @ GPIO33

// Digital INPUT
//  Yellow_button @ GPIO25
//  Red_button    @ GPIO16
//  Rotary_button @ GPIO27
//  Rotary Encoder  DT@ GPIO 

// Digital OUTPUT
//  PWM control @ GPIO14
//  Fan control @ GPIO2


LiquidCrystal_I2C lcd(0x27, 16, 4);
void setup() {
  // put your setup code here, to run once:
  lcd.begin();
  lcd.backlight();

}

void loop() {
  // put your main code here, to run repeatedly:

}

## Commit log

2025-04-01 add KiCAD
    [Controller.kicad_sch, Electronic_load_esp32.kicad_pcb, Electronic_load_esp32.kicad_sch]
2025-10-31 Update README with schematics and images
    Added schematics and additional images to README.
2025-11-03 Update Constant Current feature description in README
    Clarified the maximum current specification for Constant Current feature.
2026-08-09 Added Local Library
    - ADS1X15
    - ButtonFever
    - LiquidCrystal_I2C
    - PID
2026-08-13 Update electronic_load_codeESP32_PID.ino
    -Changed Voltage minimum to disable (onLoad) status.
    -Changed consKi from 450 to 400
2026-10-14 Refactor PID sketch display and UI modules
2026-10-14 fix(firmware): tolerate brief temperature sensor glitches
2026-10-14 fix(firmware): stabilize Battery Capacity and sensor handling
2026-10-14 docs: document Battery Capacity fixes and ADC finding
2026-10-14 feat(firmware): bound editable PID gain ranges
2026-10-14 docs: align PID defaults and gain limits
